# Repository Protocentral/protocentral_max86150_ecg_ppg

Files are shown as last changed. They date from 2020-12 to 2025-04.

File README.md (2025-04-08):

Protocentral MAX86150 PPG & ECG sensor
======================================



## Don't have one? [Buy it here](https://protocentral.com/product/protocentral-max86150-ppg-and-ecg-breakout-with-qwiic-v2/)

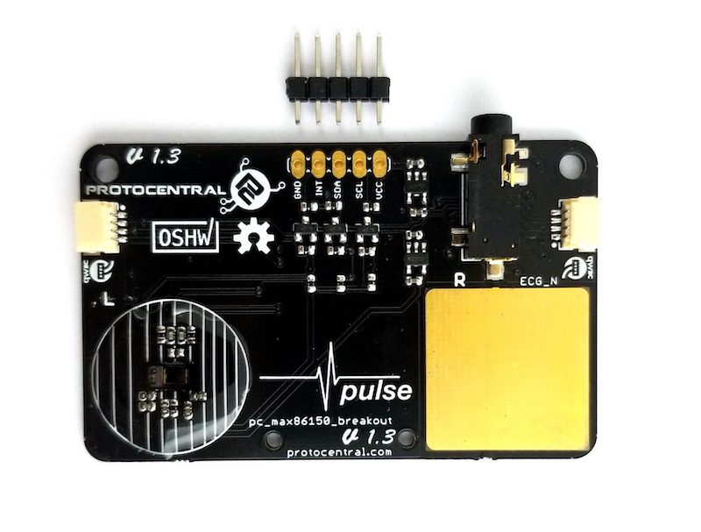
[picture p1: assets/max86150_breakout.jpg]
*Protocentral MAX86150 PPG & ECG sensor breakout*


The MAX86150 breakout board is an all in one module that supports a trio of functions for human vitals monitoring. It integrates the Pulse oximeter (SPO2), Electrocardiogram (ECG) and Heart rate sensor module into this breakout board. In more scientific terms, it is integrated with the Photoplethysmogram and Electrocardiogram biosensor module.

What makes this breakout exceptional is that it is the only touch-based module available to detect both SPO2 as well as ECG. The breakout board allows Qwiic connect as well as breadboard mounting with the provided pins. It is designed to accommodate both the ECG touchpad and the external ECG stereo connector. However, they are configured in a way that they function in an exclusive manner when one mode is active the other remains passive. Any microcontroller such as Arduino is compatible and the communication protocol used is I2C to stream data. With all the above features, this board is best suited for any Mobile health monitoring as well as in wearable devices.

## Hardware Setup

Connection with the Arduino board is as follows:
 
 |MAX86150 pin label| Arduino Connection  |Pin Function      |
 |:-----------------: |:---------------------:|:------------------:|
 | SDA              | SDA                  |  Serial Data     |
 | SCL              | SCL                  |  Serial Clock    |
 | 5V               | 5V                  |  Power           |
 | GND              | GND                 |  GND             |
 | INT              | --                  |  Interrupt            |

## Visualizing Output

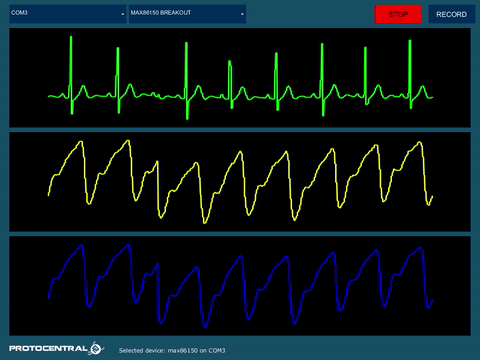
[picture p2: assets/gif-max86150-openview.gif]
streaming in openview


## For further details, refer [the documentation on MAX86150 PPG & ECG sensor](https://docs.protocentral.com/getting-started-with-max86150/)

License Information
===================

License

This product is open source! Both, our hardware and software are open source and licensed under the following licenses:

Hardware
---------

**All hardware is released under the [CERN-OHL-P v2](https://ohwr.org/cern_ohl_p_v2.txt)** license.

Copyright CERN 2020.

This source describes Open Hardware and is licensed under the CERN-OHL-P v2.

You may redistribute and modify this documentation and make products
using it under the terms of the CERN-OHL-P v2 (https:/cern.ch/cern-ohl).
This documentation is distributed WITHOUT ANY EXPRESS OR IMPLIED
WARRANTY, INCLUDING OF MERCHANTABILITY, SATISFACTORY QUALITY
AND FITNESS FOR A PARTICULAR PURPOSE. Please see the CERN-OHL-P v2
for applicable conditions

Software
--------

**All software is released under the MIT License(http://opensource.org/licenses/MIT).**

THE SOFTWARE IS PROVIDED "AS IS", WITHOUT WARRANTY OF ANY KIND, EXPRESS OR IMPLIED, INCLUDING BUT NOT LIMITED TO THE WARRANTIES OF MERCHANTABILITY, FITNESS FOR A PARTICULAR PURPOSE AND NONINFRINGEMENT. IN NO EVENT SHALL THE AUTHORS OR COPYRIGHT HOLDERS BE LIABLE FOR ANY CLAIM, DAMAGES OR OTHER LIABILITY, WHETHER IN AN ACTION OF CONTRACT, TORT OR OTHERWISE, ARISING FROM, OUT OF OR IN CONNECTION WITH THE SOFTWARE OR THE USE OR OTHER DEALINGS IN THE SOFTWARE.

Documentation
-------------
**All documentation is released under [Creative Commons Share-alike 4.0 International](http://creativecommons.org/licenses/by-sa/4.0/).**


You are free to:

* Share — copy and redistribute the material in any medium or format
* Adapt — remix, transform, and build upon the material for any purpose, even commercially.
The licensor cannot revoke these freedoms as long as you follow the license terms.

Under the following terms:

* Attribution — You must give appropriate credit, provide a link to the license, and indicate if changes were made. You may do so in any reasonable manner, but not in any way that suggests the licensor endorses you or your use.
* ShareAlike — If you remix, transform, or build upon the material, you must distribute your contributions under the same license as the original.

Please check [*LICENSE.md*](LICENSE.md) for detailed license descriptions.

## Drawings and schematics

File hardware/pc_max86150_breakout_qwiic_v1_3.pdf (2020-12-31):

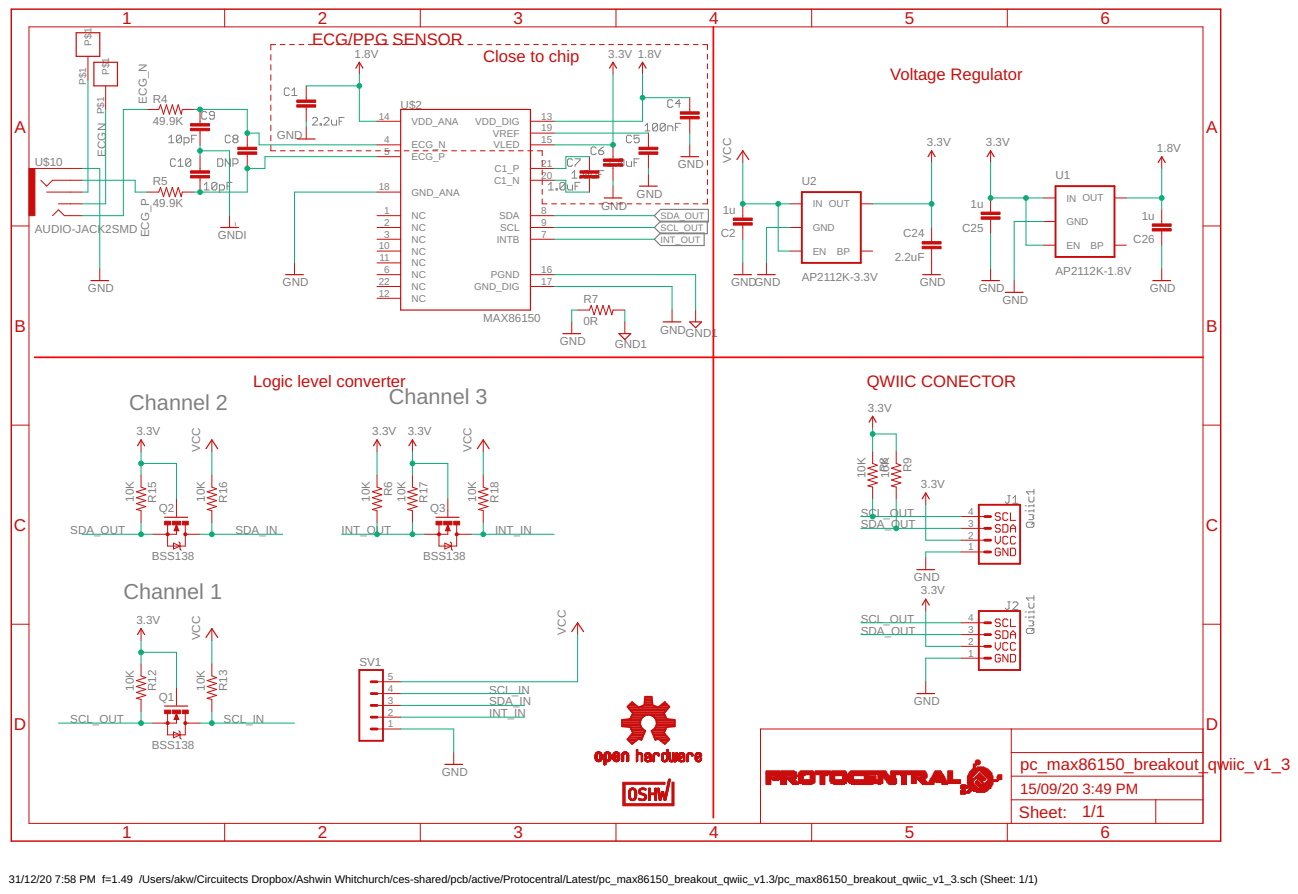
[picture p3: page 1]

31/12/20 7:58 PM f=1.49 /Users/akw/Circuitects Dropbox/Ashwin Whitchurch/ces-shared/pcb/active/Protocentral/Latest/pc_max86150_breakout_qwiic_v1.3/pc_max86150_breakout_qwiic_v1_3.sch (Sheet: 1/1)

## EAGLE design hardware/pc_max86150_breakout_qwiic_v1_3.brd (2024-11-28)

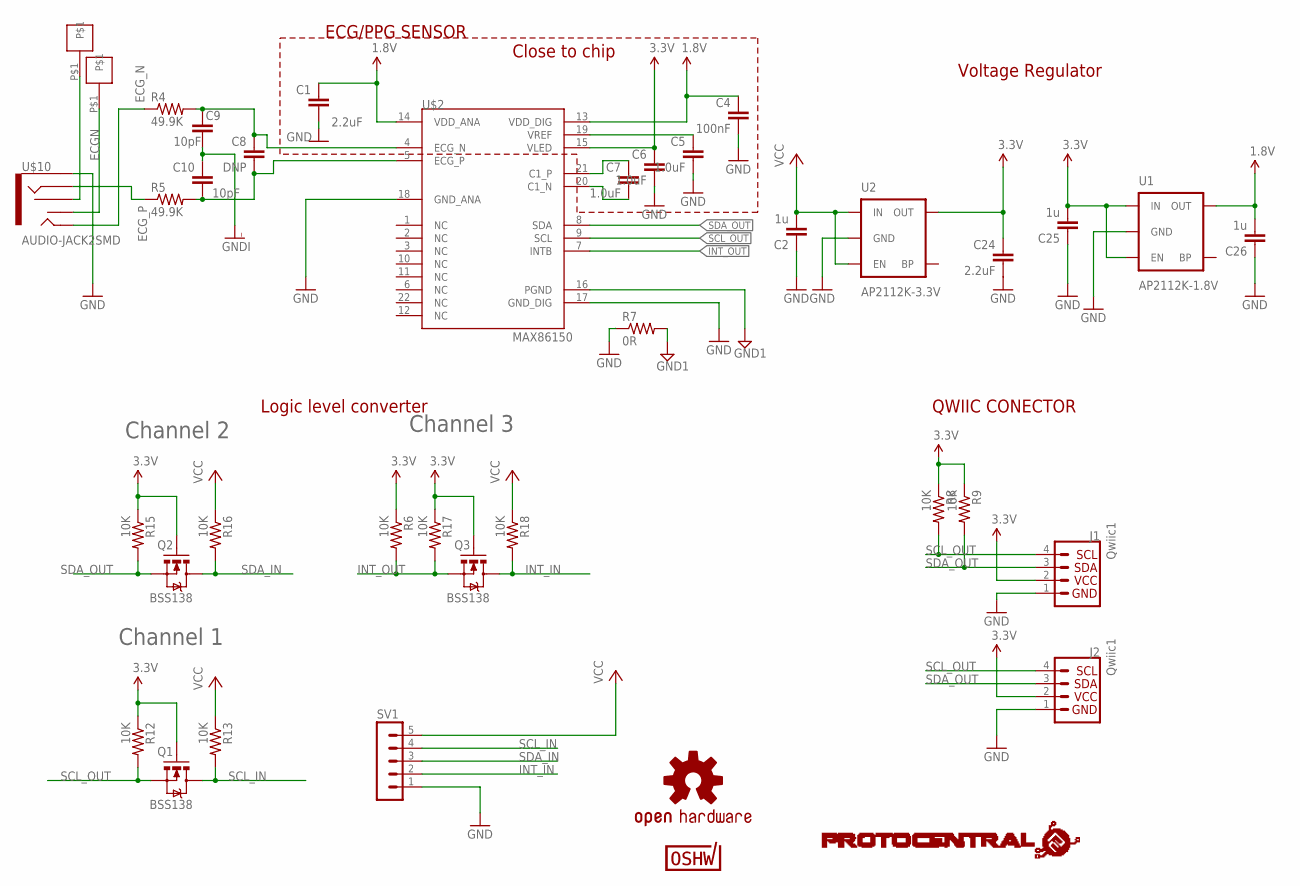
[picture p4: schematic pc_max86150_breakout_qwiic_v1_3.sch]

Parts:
C1: 2.2uF; 0402
C2, C25, C26: 1u; C0402
C4: 100nF; 0402
C5, C6, C7: 1.0uF; 0402
C8: DNP; 0402
C9, C10: 10pF; 0402
C24: 2.2uF; C0402
J1, J2: Qwiic1; 1X04_1MM_RA
Q1, Q2, Q3: BSS138; SOT23-3
R4, R5: 49.9K; 0402-RES
R6, R8, R9, R12, R13, R15, R16, R17, R18: 10K; 0402-RES
R7: 0R; 0402-RES
SV1: MA05-1
U1: AP2112K-1.8V; SOT23-5
U2: AP2112K-3.3V; SOT23-5
U$2: MAX86150
U$3: PROTY_LOGO_WITH_TEXT; PROTY_WITH_TEXT
U$4, U$13: ECG_PAD; ECG_PAD1
U$10: AUDIO-JACK2SMD; AUDIO-JACK-3.5MM-SMD
U$12: OSHW-LOGOM; OSHW-LOGO-M
U$17: CERT-SMALL; CERT-SMALL-SILK

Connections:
1.8V: C1.1, C4.1, C26.2, U1.5 (OUT), U$2.13 (VDD_DIG), U$2.14 (VDD_ANA)
3.3V: C6.1, C24.1, C25.2, J1.2, J2.2, Q1.1 (G), Q2.1 (G), Q3.1 (G), R6.1, R8.1, R9.1, R12.1, R15.1, R17.1, U1.1 (IN), U1.3 (EN), U2.5 (OUT), U$2.15 (VLED)
@: U$4.P$1, U$10.RSH
ECGN: U$10.TSH, U$13.P$1
ECG_N: R4.1, U$10.TIP
ECG_P: R5.1, U$10.RING
GND: C1.2, C2.1, C4.2, C5.2, C6.2, C24.2, C25.1, C26.1, J1.1, J2.1, R7.1, SV1.1, U1.2 (GND), U2.2 (GND), U$2.17 (GND_DIG), U$2.18 (GND_ANA), U$10.SLEEVE
GND1: R7.2, U$2.16 (PGND)
GNDI: C9.2, C10.1
INT_IN: Q3.3 (D), R18.2, SV1.2
INT_OUT: Q3.2 (S), R6.2, R17.2, U$2.7 (INTB)
unnamed: C7.1, U$2.21 (C1_P)
unnamed: C7.2, U$2.20 (C1_N)
unnamed: C8.1, C9.1, R4.2, U$2.4 (ECG_N)
unnamed: C5.1, U$2.19 (VREF)
unnamed: C8.2, C10.2, R5.2, U$2.5 (ECG_P)
SCL_IN: Q1.3 (D), R13.2, SV1.4
SCL_OUT: J1.4, J2.4, Q1.2 (S), R8.2, R12.2, U$2.9 (SCL)
SDA_IN: Q2.3 (D), R16.2, SV1.3
SDA_OUT: J1.3, J2.3, Q2.2 (S), R9.2, R15.2, U$2.8 (SDA)
VCC: C2.2, R13.1, R16.1, R18.1, SV1.5, U2.1 (IN), U2.3 (EN)

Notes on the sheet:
Channel 1
Channel 2
Channel 3
Voltage Regulator
ECG/PPG SENSOR
Logic level converter
QWIIC CONECTOR
Close to chip

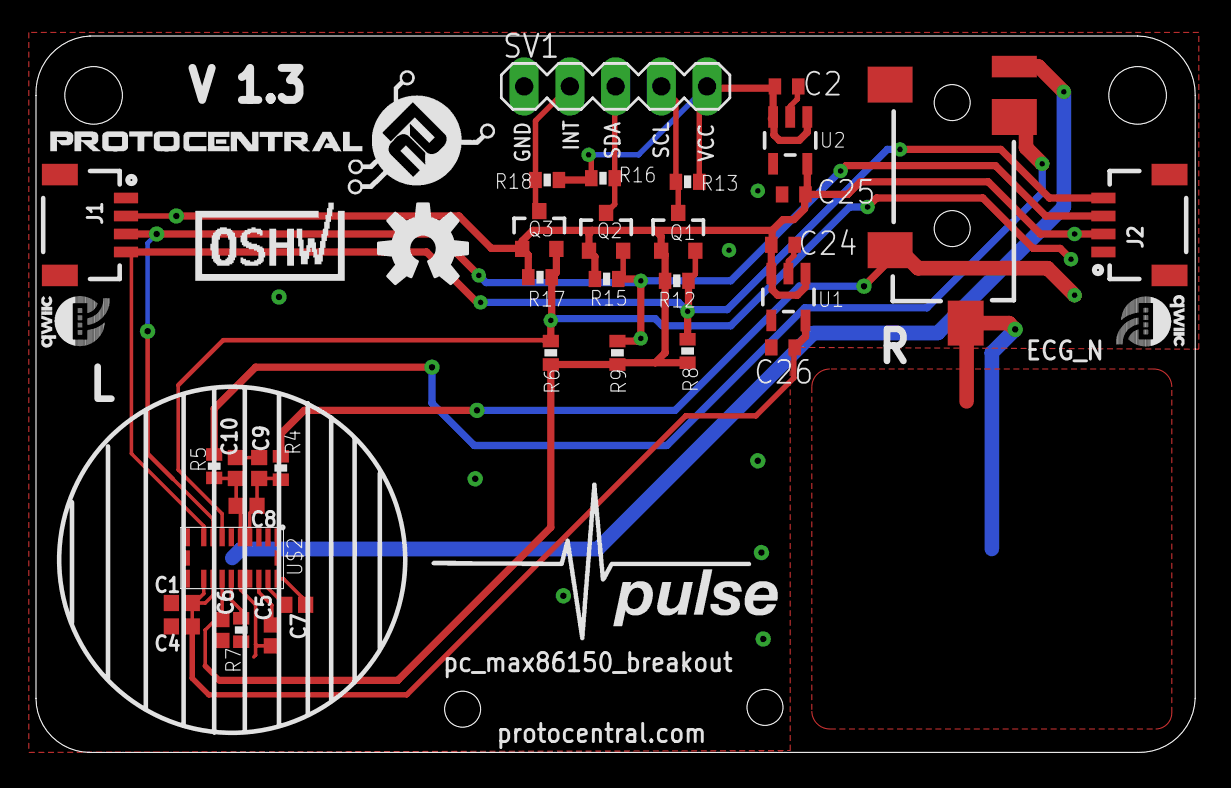
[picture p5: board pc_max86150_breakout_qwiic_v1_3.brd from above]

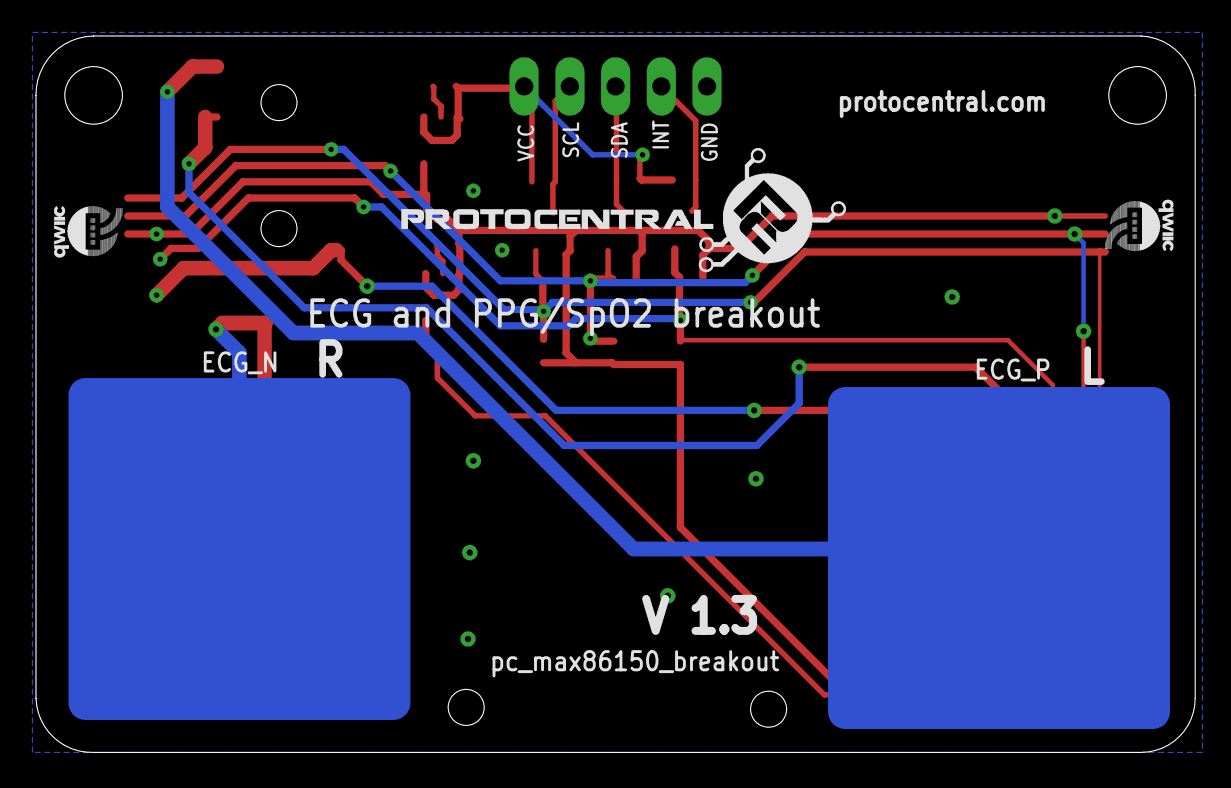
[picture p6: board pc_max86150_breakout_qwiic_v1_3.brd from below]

Board: 4 copper layers, 64.4 x 39.8 mm, 45 parts (5 on the bottom side), 21 nets.

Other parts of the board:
U$1: PULSE
U$6, U$9, U$11, U$59: QWIIC#LABEL#FULL#M#PNG
U$7: PROTY_LOGO_WITH_TEXT; PROTY_WITH_TEXT

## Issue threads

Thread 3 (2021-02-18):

not getting reliable readings from max86150

anuragadspl, 2021-02-18:
The data i am getting is very poor and not reliable . Also the code does not calculate anything like heartbeat or spo2 or any important parameter by which its accuracy or reliability can be determined.Als.o openview is not working data is being not updated

joicetm, 2021-02-19:
Hi anuragdspl,

The demonstration examples does not have any algorithms to calculate the spo2 or hr but you may use any open source algorithms to calculate them.
You can have a look at the [afe4490 library ](https://github.com/Protocentral/protocentral-afe4490-arduino/tree/main/examples/Example-2-computed-spo2) for spo2 calculations and [ads1292 library ](https://github.com/Protocentral/protocentral-ads1292r-arduino) for the hr calculations.

We will try to integrate the calculations in the future to the library but i can't promise you when this will be implemented.

Can you please specify which data you find not reliable ? is it the ppg signal or the ECG ?
The ECG data from the pads may not be of good quality but the data from the ECG connector will be of good quality.
Please make sure you have proper shielding on the LED and finger While trying to read ppg signal.

can you please share some ECG and PPG waveform you are getting and also some photos of you finger placement on the LED?

Would  you also  elaborate on the openview issue please ? which is your system os? what is the output you are able to view? some screen-shots will be helpful.

We are sorry that you couldn't use it hassle free, we will keep on working to make sure these kind of issues are fixed ASAP.

mvnsgupta, 2021-10-14:
Dear Sir, Sometimes, the red LED is not turning on. May I please know what could be the issue?
I am giving a 5V supply from the Arduino UNO board.

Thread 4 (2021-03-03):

Recorded PPG Signals looks clipped

niv22, 2021-03-03:
Hello,
We were testing the PPG signal of the sensor. We were able to see signal correctly in the Openview GUI. But the saved signal appears clipped or quantized as shown in the image below. (The plot is generated in python using matplotlib)
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

The PPG data looks like this:
...
 231.0,
 231.0,
 231.0,
 226.0,
 226.0,
 226.0,
 226.0,
 228.0,
 228.0,
 228.0,
 228.0,
 228.0,
 228.0,
 228.0,
 228.0,
...
It can be observed that each value is being repeated four times and there is significant difference between the non-repeating values which does not result in a smooth signal. Is there some processing that we need to do once we record the signal in-order to get the proper waveform?

diegotorpoco, 2021-05-25:
Hello, could you solve this issue? I have a similar graph for the ECG signal, as if it was a discrete signal.

joicetm, 2021-05-26:
Hi,

It looks like oversampling, have you made any changes to the library ?
can you please share your code and some images of your output ?

diegotorpoco, 2021-05-26:
Hi,

I have fixed the issue by disconnecting the laptop's battery. It seems that it was causing a noise. Now I have a better EKG signal compared to before . This has been filtered already.

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

joicetm, 2021-05-26:
Great, we are glad that you were able to fix the issue.
AC noise will cause distortion to the signal.

Closed 2021-05-26.

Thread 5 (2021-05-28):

setSampleRate

DiegoPaezA, 2021-05-28:
Hi,

Thanks for the library it is a good resource for my project.  I am trying to change the samplerate, but the function is disabled. when trying to use I find that the MAX86150_PARTICLECONFIG register is not found in the library.

What recommendation do you give me to adjust this function?

joicetm, 2021-06-01:
You can make pull request If you are able fix that issue.
We can review and publish a new version with the changes.

Please let me know if you have any question.

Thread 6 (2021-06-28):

void setup() function doesn't seem to change User settings

anuragpareto, 2021-06-28:
I have tried changing this line in header:

`  void setup(byte powerLevel = 0x1F, byte sampleAverage = 4, byte ledMode = 3, int sampleRate = 400, int pulseWidth = 411, int adcRange = 4096);
`

For different Sampling rate and Averaging
But, It always gives 4 samples with same value and same number of data samples in a second.

For instance, it always follows this pattern:

> 14:14:28.371 -> 201
14:14:28.371 -> 201
14:14:28.371 -> 201
14:14:28.371 -> 201
14:14:28.371 -> 214
14:14:28.411 -> 214
14:14:28.411 -> 214
14:14:28.411 -> 214
14:14:28.411 -> 261
14:14:28.411 -> 261
14:14:28.411 -> 261
14:14:28.411 -> 261
14:14:28.411 -> 286
14:14:28.445 -> 286
14:14:28.445 -> 286
14:14:28.445 -> 286
14:14:28.445 -> 229
14:14:28.445 -> 229
14:14:28.445 -> 229
14:14:28.482 -> 229
14:14:28.482 -> 186
14:14:28.482 -> 186
14:14:28.482 -> 186
14:14:28.482 -> 186
14:14:28.482 -> 210
14:14:28.482 -> 210
14:14:28.482 -> 210
14:14:28.525 -> 210

As you can see, it always repeats 4 values like above 210, 186 etc.
Which results in flat lines on graph.
Another issue is if I try to change Sampling rate, it still gives same number of data samples.
Like from 14:14:28.411 to 14:14:28.482, it gives 22 samples, which makes it 22x10 = 220/Sec approx
Even though, I chose 1000 sampling rate.

Is there anything I am missing here?

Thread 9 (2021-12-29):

ECG Readings seem to be incorrect

lambo81, 2021-12-29:
I am running Example 2 with an Arduino UNO clone (Elegoo UNO R3).  I did not use the QWIIC connector but instead manually connected:

GND->GND
VCC->5V
SDA->SDA
SCL->SCL

I believe the default sampling rate is 200 hz, correct?  I am touching the dry contacts with my right and left hand. Here is some of the data I am getting:

timestamp,ecg_measurement
5.0,0
10.0,0
15.0,-2072
20.0,-2072
25.0,-2072
30.0,-11205
35.0,-11205
40.0,-11205
45.0,-11205
50.0,-17871
55.0,-17871
60.0,-17871
65.0,-17871
70.0,-7851
75.0,-7851
80.0,-7851
85.0,-7851
90.0,-615

here is also a screenshot of the plot of the data

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

JinaLeeIMS, 2022-09-16:
Hi, let me see your code for getting ECG data

vivekkumar1912, 2023-07-12:
sample rate of both is 200 |  
-- | --
ECG | PPG
6419 | 5289
6402 | 5083
6402 | 5083
6402 | 5083
6402 | 5083
2503 | 5045
2503 | 5045
2503 | 5045
2503 | 5045
2598 | 5051
2598 | 5051
2598 | 5051
2598 | 5051
-1637 | 5118
-1637 | 5118
-1637 | 5118
-1637 | 5118
-1825 | 5173
-1825 | 5173
-1825 | 5173
-1825 | 5173
537 | 5239
537 | 5239
537 | 5239
537 | 5239
379 | 5240
379 | 5240
379 | 5240
379 | 5240
483 | 5252
483 | 5252
483 | 5252
483 | 5252
5814 | 5278
5814 | 5278
5814 | 5278
5814 | 5278
5754 | 5305
5754 | 5305
5754 | 5305
5754 | 5305
5567 | 5405
5567 | 5405

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

i get ppg data properly but i does not get ecg data properly.

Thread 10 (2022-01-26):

Information Needed About max86150

shoaibAutomationEngineer, 2022-01-26:
It will be very comfortable if there is detailed documentation about the sensor. For example how to place hands on pads for taking ECG readings. I have tried all possible combinations with but reading from onboard sensor pads it not giving correct ECG readings. Also there is no documentation or tutorials available. Further examples in the GitHub repo are not enough. For example there are no examples about SPO2 and heartrate. In addition i have tried OpenView GUI even its not working. I wish all these bottlenecks to be removed so we can further evaluate the sensor.

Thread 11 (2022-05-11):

PCB Files for 0.1.3

amansinghaljpr, 2022-05-11:
I want to have the PCB design files for the release 0.1.3

manikandan12345, 2022-05-11:
Hi Amansingh, it is in zip format under Hardware file ,please  extract and check (.BRD and .SCH)
[pc_max86150_breakout_qwiic_v1_3.zip](https://github.com/Protocentral/protocentral_max86150_ecg_ppg/files/8670598/pc_max86150_breakout_qwiic_v1_3.zip)

amansinghaljpr, 2022-05-11:
> Hi Amansingh, it is in zip format under Hardware file ,please extract and check (.BRD and .SCH) [pc_max86150_breakout_qwiic_v1_3.zip](https://github.com/Protocentral/protocentral_max86150_ecg_ppg/files/8670598/pc_max86150_breakout_qwiic_v1_3.zip)

Hey i checked it , this PCB design refers to the latest PCB which is already there in the repository . I want the files for the older version of the PCB , i am attaching the pictures of it below .

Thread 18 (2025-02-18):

I have trouble with Arduino Portenta X8

tolgahayit, 2025-02-18:
Hi all,
I am able to make connection between Arduino sketch and linux right now.
But I have another problem.
I bought ProtoCentral MAX86150 PPG and ECG breakout about 3 moths ago, I tried to connect that sensor with Portenta X8 but couldn't.
And I also dropped my setup below. I use I2C protocol (Black cable to GND, Blue cable to SDA, Yellow cable to SCL and Red cable to VCC)
I think there is no signal from the sensor.

I followed this example:
https://docs.arduino.cc/tutorials/portenta-x8/python-arduino-data-exchange/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

I appreciated if any suggestions.

Thanks

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

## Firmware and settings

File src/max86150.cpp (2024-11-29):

/***************************************************
  Arduino library written for the Maxim MAX86150 ECG and PPG integrated sensor

	Written by Ashwin Whitchurch, ProtoCentral Electronics (www.protocentral.com)

  Based on code written by Peter Jansen and Nathan Seidle (SparkFun) for the MAX30105 sensor
  BSD license, all text above must be included in any redistribution.
 *****************************************************/

#include "max86150.h"

static const uint8_t MAX86150_INTSTAT1 =		0x00;
static const uint8_t MAX86150_INTSTAT2 =		0x01;
static const uint8_t MAX86150_INTENABLE1 =		0x02;
static const uint8_t MAX86150_INTENABLE2 =		0x03;

static const uint8_t MAX86150_FIFOWRITEPTR = 	0x04;
static const uint8_t MAX86150_FIFOOVERFLOW = 	0x05;
static const uint8_t MAX86150_FIFOREADPTR = 	0x06;
static const uint8_t MAX86150_FIFODATA 		=		0x07;

static const uint8_t MAX86150_FIFOCONFIG = 		0x08;
static const uint8_t MAX86150_FIFOCONTROL1= 	0x09;
static const uint8_t MAX86150_FIFOCONTROL2 = 	0x0A;

static const uint8_t MAX86150_SYSCONTROL = 	0x0D;
static const uint8_t MAX86150_PPGCONFIG1 = 		0x0E;
static const uint8_t MAX86150_PPGCONFIG2 = 		0x0F;
static const uint8_t MAX86150_LED_PROX_AMP = 	0x10;

static const uint8_t MAX86150_LED1_PULSEAMP = 	0x11;
static const uint8_t MAX86150_LED2_PULSEAMP = 	0x12;
static const uint8_t MAX86150_LED_RANGE 		= 	0x14;
static const uint8_t MAX86150_LED_PILOT_PA 	= 	0x15;

static const uint8_t MAX86150_ECG_CONFIG1 	= 	0x3C;
static const uint8_t MAX86150_ECG_CONFIG3 	= 	0x3E;
static const uint8_t MAX86150_PROXINTTHRESH = 	0x10;

static const uint8_t MAX86150_PARTID = 			0xFF;

// MAX86150 Commands
static const uint8_t MAX86150_INT_A_FULL_MASK =		(byte)~0b10000000;
static const uint8_t MAX86150_INT_A_FULL_ENABLE = 	0x80;
static const uint8_t MAX86150_INT_A_FULL_DISABLE = 	0x00;

static const uint8_t MAX86150_INT_DATA_RDY_MASK = (byte)~0b01000000;
static const uint8_t MAX86150_INT_DATA_RDY_ENABLE =	0x40;
static const uint8_t MAX86150_INT_DATA_RDY_DISABLE = 0x00;

static const uint8_t MAX86150_INT_ALC_OVF_MASK = (byte)~0b00100000;
static const uint8_t MAX86150_INT_ALC_OVF_ENABLE = 	0x20;
static const uint8_t MAX86150_INT_ALC_OVF_DISABLE = 0x00;

static const uint8_t MAX86150_INT_PROX_INT_MASK = (byte)~0b00010000;
static const uint8_t MAX86150_INT_PROX_INT_ENABLE = 0x10;
static const uint8_t MAX86150_INT_PROX_INT_DISABLE = 0x00;

static const uint8_t MAX86150_SAMPLEAVG_MASK =	(byte)~0b11100000;
static const uint8_t MAX86150_SAMPLEAVG_1 = 	0x00;
static const uint8_t MAX86150_SAMPLEAVG_2 = 	0x20;
static const uint8_t MAX86150_SAMPLEAVG_4 = 	0x40;
static const uint8_t MAX86150_SAMPLEAVG_8 = 	0x60;
static const uint8_t MAX86150_SAMPLEAVG_16 = 	0x80;
static const uint8_t MAX86150_SAMPLEAVG_32 = 	0xA0;

static const uint8_t MAX86150_ROLLOVER_MASK = 	0xEF;
static const uint8_t MAX86150_ROLLOVER_ENABLE = 0x10;
static const uint8_t MAX86150_ROLLOVER_DISABLE = 0x00;

static const uint8_t MAX86150_A_FULL_MASK = 	0xF0;

static const uint8_t MAX86150_SHUTDOWN_MASK = 	0xFD;
static const uint8_t MAX86150_SHUTDOWN = 		0x02;
static const uint8_t MAX86150_WAKEUP = 			0x00;

static const uint8_t MAX86150_RESET_MASK = 		0xFE;
static const uint8_t MAX86150_RESET = 			0x01;

static const uint8_t MAX86150_MODE_MASK = 		0xF8;
static const uint8_t MAX86150_MODE_REDONLY = 	0x02;
static const uint8_t MAX86150_MODE_REDIRONLY = 	0x03;
static const uint8_t MAX86150_MODE_MULTILED = 	0x07;

static const uint8_t MAX86150_ADCRANGE_MASK = 	0x9F;
static const uint8_t MAX86150_ADCRANGE_2048 = 	0x00;
static const uint8_t MAX86150_ADCRANGE_4096 = 	0x20;
static const uint8_t MAX86150_ADCRANGE_8192 = 	0x40;
static const uint8_t MAX86150_ADCRANGE_16384 = 	0x60;

static const uint8_t MAX86150_SAMPLERATE_MASK = 0xE3;
static const uint8_t MAX86150_SAMPLERATE_50 = 	0x00;
static const uint8_t MAX86150_SAMPLERATE_100 = 	0x04;
static const uint8_t MAX86150_SAMPLERATE_200 = 	0x08;
static const uint8_t MAX86150_SAMPLERATE_400 = 	0x0C;
static const uint8_t MAX86150_SAMPLERATE_800 = 	0x10;
static const uint8_t MAX86150_SAMPLERATE_1000 = 0x14;
static const uint8_t MAX86150_SAMPLERATE_1600 = 0x18;
static const uint8_t MAX86150_SAMPLERATE_3200 = 0x1C;

static const uint8_t MAX86150_PULSEWIDTH_MASK = 0xFC;
static const uint8_t MAX86150_PULSEWIDTH_69 = 	0x00;
static const uint8_t MAX86150_PULSEWIDTH_118 = 	0x01;
static const uint8_t MAX86150_PULSEWIDTH_215 = 	0x02;
static const uint8_t MAX86150_PULSEWIDTH_411 = 	0x03;

static const uint8_t MAX86150_SLOT1_MASK = 		0xF0;
static const uint8_t MAX86150_SLOT2_MASK = 		0x0F;
static const uint8_t MAX86150_SLOT3_MASK = 		0xF0;
static const uint8_t MAX86150_SLOT4_MASK = 		0x0F;

static const uint8_t SLOT_NONE 				= 			0x00;
static const uint8_t SLOT_RED_LED 		= 			0x01;
static const uint8_t SLOT_IR_LED 			= 			0x02;
static const uint8_t SLOT_RED_PILOT 	=				0x09;
static const uint8_t SLOT_IR_PILOT 		= 			0x0A;
static const uint8_t SLOT_ECG					= 			0x0D;

static const uint8_t MAX_30105_EXPECTEDPARTID = 0x1E;

MAX86150::MAX86150() {
  // Constructor
}

boolean MAX86150::begin(TwoWire &wirePort, uint32_t i2cSpeed, uint8_t i2caddr)
{
  _i2cPort = &wirePort; //Grab which port the user wants us to use

  _i2cPort->begin();
  _i2cPort->setClock(i2cSpeed);

  _i2caddr = i2caddr;

  // Step 1: Initial Communication and Verification
  // Check that a MAX86150 is connected
  if (readPartID() != MAX_30105_EXPECTEDPARTID) {
    // Error -- Part ID read from MAX86150 does not match expected part ID.
    // This may mean there is a physical connectivity problem (broken wire, unpowered, etc).
    return false;
  }
  return true;
}

//
// Configuration
//

//Begin Interrupt configuration
uint8_t MAX86150::getINT1(void)
{
  return (readRegister8(_i2caddr, MAX86150_INTSTAT1));
}
uint8_t MAX86150::getINT2(void) {
  return (readRegister8(_i2caddr, MAX86150_INTSTAT2));
}

void MAX86150::enableAFULL(void) {
  bitMask(MAX86150_INTENABLE1, MAX86150_INT_A_FULL_MASK, MAX86150_INT_A_FULL_ENABLE);
}
void MAX86150::disableAFULL(void) {
  bitMask(MAX86150_INTENABLE1, MAX86150_INT_A_FULL_MASK, MAX86150_INT_A_FULL_DISABLE);
}

void MAX86150::enableDATARDY(void) {
  bitMask(MAX86150_INTENABLE1, MAX86150_INT_DATA_RDY_MASK, MAX86150_INT_DATA_RDY_ENABLE);
}
void MAX86150::disableDATARDY(void) {
  bitMask(MAX86150_INTENABLE1, MAX86150_INT_DATA_RDY_MASK, MAX86150_INT_DATA_RDY_DISABLE);
}

void MAX86150::enableALCOVF(void) {
  bitMask(MAX86150_INTENABLE1, MAX86150_INT_ALC_OVF_MASK, MAX86150_INT_ALC_OVF_ENABLE);
}
void MAX86150::disableALCOVF(void) {
  bitMask(MAX86150_INTENABLE1, MAX86150_INT_ALC_OVF_MASK, MAX86150_INT_ALC_OVF_DISABLE);
}

void MAX86150::enablePROXINT(void) {
  bitMask(MAX86150_INTENABLE1, MAX86150_INT_PROX_INT_MASK, MAX86150_INT_PROX_INT_ENABLE);
}
void MAX86150::disablePROXINT(void) {
  bitMask(MAX86150_INTENABLE1, MAX86150_INT_PROX_INT_MASK, MAX86150_INT_PROX_INT_DISABLE);
}
//End Interrupt configuration
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

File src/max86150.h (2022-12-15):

/***************************************************
  Arduino library written for the Maxim MAX86150 ECG and PPG integrated sensor

	Written by Ashwin Whitchurch, ProtoCentral Electronics (www.protocentral.com)

	https://github.com/protocentral/protocentral_max86150

  Based on code written by Peter Jansen and Nathan Seidle (SparkFun) for the MAX30105 sensor
  BSD license, all text above must be included in any redistribution.
 *****************************************************/

#pragma once

#if (ARDUINO >= 100)
 #include "Arduino.h"
#else
 #include "WProgram.h"
#endif

#include <Wire.h>

#define MAX86150_ADDRESS          0x5E //7-bit I2C Address
//Note that MAX30102 has the same I2C address and Part ID

#define I2C_SPEED_STANDARD        100000
#define I2C_SPEED_FAST            400000

//Define the size of the I2C buffer based on the platform the user has
#if defined(__AVR_ATmega328P__) || defined(__AVR_ATmega168__)

  //I2C_BUFFER_LENGTH is defined in Wire.H
  #define I2C_BUFFER_LENGTH BUFFER_LENGTH

#elif defined(__SAMD21G18A__)

  //SAMD21 uses RingBuffer.h
  #define I2C_BUFFER_LENGTH SERIAL_BUFFER_SIZE

#else

  //The catch-all default is 32
  #define I2C_BUFFER_LENGTH 32

#endif

class MAX86150 {
 public:
  MAX86150(void);

  boolean begin(TwoWire &wirePort = Wire, uint32_t i2cSpeed = I2C_SPEED_STANDARD, uint8_t i2caddr = MAX86150_ADDRESS);

  uint32_t getRed(void); //Returns immediate red value
  uint32_t getIR(void); //Returns immediate IR value
  int32_t getECG(void); //Returns immediate ECG value
  bool safeCheck(uint8_t maxTimeToCheck); //Given a max amount of time, check for new data

  // Configuration
  void softReset();
  void shutDown();
  void wakeUp();

  void setLEDMode(uint8_t mode);

  void setADCRange(uint8_t adcRange);
  void setSampleRate(uint8_t sampleRate);
  void setPulseWidth(uint8_t pulseWidth);

  void setPulseAmplitudeRed(uint8_t value);
  void setPulseAmplitudeIR(uint8_t value);
  void setPulseAmplitudeProximity(uint8_t value);

  void setProximityThreshold(uint8_t threshMSB);

  //Multi-led configuration mode (page 22)
  void enableSlot(uint8_t slotNumber, uint8_t device); //Given slot number, assign a device to slot
  void disableSlots(void);

  // Data Collection

  //Interrupts (page 13, 14)
  uint8_t getINT1(void); //Returns the main interrupt group
  uint8_t getINT2(void); //Returns the temp ready interrupt
  void enableAFULL(void); //Enable/disable individual interrupts
  void disableAFULL(void);
  void enableDATARDY(void);
  void disableDATARDY(void);
  void enableALCOVF(void);
  void disableALCOVF(void);
  void enablePROXINT(void);
  void disablePROXINT(void);
  void enableDIETEMPRDY(void);
  void disableDIETEMPRDY(void);

  //FIFO Configuration (page 18)
  void setFIFOAverage(uint8_t samples);
  void enableFIFORollover();
  void disableFIFORollover();
  void setFIFOAlmostFull(uint8_t samples);

  //FIFO Reading
  uint16_t check(void); //Checks for new data and fills FIFO
  uint8_t available(void); //Tells caller how many new samples are available (head - tail)
  void nextSample(void); //Advances the tail of the sense array
  uint32_t getFIFORed(void); //Returns the FIFO sample pointed to by tail
  uint32_t getFIFOIR(void); //Returns the FIFO sample pointed to by tail
  int32_t getFIFOECG(void); //Returns the FIFO sample pointed to by tail

  uint8_t getWritePointer(void);
  uint8_t getReadPointer(void);
  void clearFIFO(void); //Sets the read/write pointers to zero

  //Proximity Mode Interrupt Threshold
  void setPROXINTTHRESH(uint8_t val);

  // Die Temperature
  float readTemperature();
  float readTemperatureF();

  // Detecting ID/Revision
  uint8_t getRevisionID();
  uint8_t readPartID();
	uint8_t readRegLED();

  // Setup the IC with user selectable settings
  void setup(byte powerLevel = 0x1F, byte sampleAverage = 4, byte ledMode = 3, int sampleRate = 400, int pulseWidth = 411, int adcRange = 4096);

  // Low-level I2C communication
  uint8_t readRegister8(uint8_t address, uint8_t reg);
  void writeRegister8(uint8_t address, uint8_t reg, uint8_t value);

 private:
  TwoWire *_i2cPort; //The generic connection to user's chosen I2C hardware
  int _i2caddr;

  //activeLEDs is the number of channels turned on, and can be 1 to 3. 2 is common for Red+IR.
  byte activeDevices; //Gets set during setup. Allows check() to calculate how many bytes to read from FIFO

  uint8_t revisionID;

  void readRevisionID();

  void bitMask(uint8_t reg, uint8_t mask, uint8_t thing);

   #define STORAGE_SIZE 4 //Each long is 4 bytes so limit this to fit on your micro
  typedef struct Record
  {
    uint32_t red[STORAGE_SIZE];
    uint32_t IR[STORAGE_SIZE];
    int32_t ecg[STORAGE_SIZE];
    byte head;
    byte tail;
  } sense_struct; //This is our circular buffer of readings from the sensor

  sense_struct sense;

};

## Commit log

2019-05-06 Added hardware files
    [pc_max86150_breakout_qwiic2part_part1.brd, pc_max86150_breakout_qwiic2part_part1.sch, pc_max86150_breakout_qwiic2part_part2.brd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]
2020-03-12 Fix include of max86150.h
    The file is named max86150.h (lower case letters), but
    it was included as MAX86150.h, causing build to fail on
    case sensitive operating systems such as Linux.
    [max86150.cpp]
2020-12-31 Updated latest hardware files
    [pc_max86150_breakout_qwiic2part_part1.brd, pc_max86150_breakout_qwiic2part_part1.sch, pc_max86150_breakout_qwiic2part_part2.brd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]
2022-02-16 Add: Filter for ECG
2022-12-15 Fixed build errors on ESP32
    [max86150.cpp, max86150.h]
2022-12-15 Fixed build errors with ESP32
    [Example1-PPG-Stream-Arduino-Plotter.ino, Example2-ECG-Stream-Arduino-Plotter.ino]
2023-04-10 Fixed shutdown & wakeup functions
    MAX86150_SHUTDOWN_MASK and MAX86150_SHUTDOWN definitions were incorrect (they were for max30102) which caused shutdown and wakeup functions not to work properly.
    [max86150.cpp]
2024-11-28 readme updated, schematic extracted, workflow updated
    [pc_max86150_breakout_qwiic_v1_3.brd, pc_max86150_breakout_qwiic_v1_3.sch]

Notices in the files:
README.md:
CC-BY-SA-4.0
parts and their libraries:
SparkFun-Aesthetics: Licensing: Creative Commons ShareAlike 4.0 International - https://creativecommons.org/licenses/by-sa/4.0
